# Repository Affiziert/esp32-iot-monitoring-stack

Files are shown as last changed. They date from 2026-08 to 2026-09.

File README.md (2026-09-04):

# ESP32 IoT Monitoring Stack

The project uses battery-powered ESP32-C3 boards as transmitters to measure temperature, relative humidity, and battery voltage. The sensor data is transmitted wirelessly via ESP-NOW to an ESP32-C3 receiver and forwarded via USB serial to a Raspberry Pi. A Python-based data bridge processes the received data and stores it in an InfluxDB database running in a Docker Compose environment.

This project can be used as a reference for integrating additional sensors and actuators.

---

## Overview

The goal of this project is to implement a lightweight and modular IoT monitoring stack using readily available hardware and open-source software.
The current implementation consists of the following components:

- ESP32-C3 transmitter node with a single Li-Ion cell (3.7 V), TP4056 charging module and voltage divider for battery voltage measurement
- SHT31 module for temperature and relative humidity measurement
- ESP32-C3 receiver node
- ESP-NOW wireless communication
- Raspberry Pi 4 as an edge gateway
- Python data bridge
- InfluxDB 2.x database

The modular architecture allows individual components to be modified or extended independently.

---

## Architecture

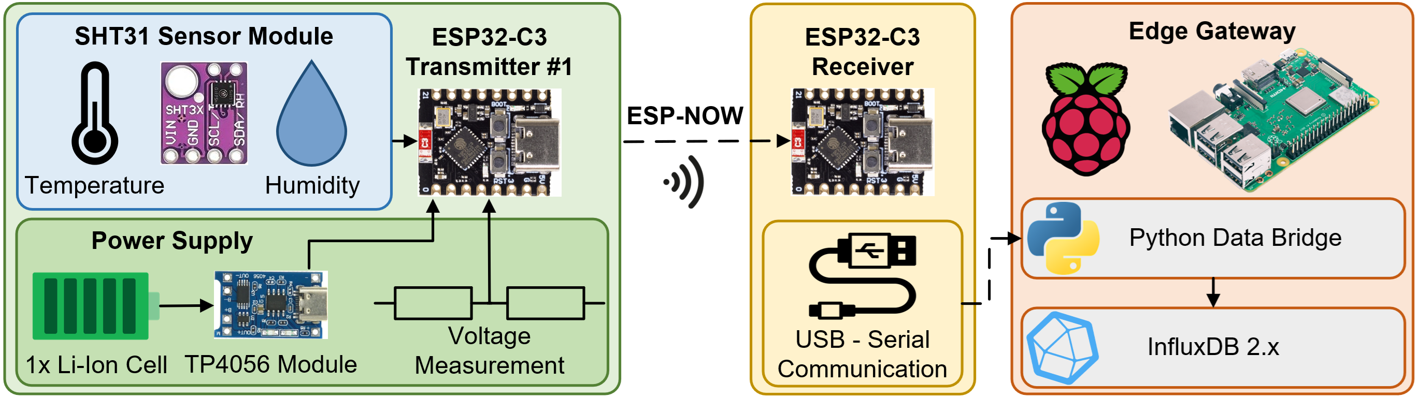
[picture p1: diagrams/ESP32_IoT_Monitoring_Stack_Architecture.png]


---

## Hardware Requirements

### Sensor Node

| Component | Quantity | Purpose |
|---|---|---|
| ESP32-C3 | 1 | Transmitter |
| SHT31 module | 1 | Temperature and relative humidity measurement |
| Li-Ion cell (3.7 V) | 1 | Power supply |
| 18650 battery holder  | 1 | Battery connection |
| TP4056 module | 1 | Li-Ion charging |
| Resistors | 2 | Voltage divider for battery voltage measurement (1 MΩ) |
| Capacitors | 1 | ADC input filtering (100 nF) |

### Receiver Node

| Component | Quantity | Purpose |
|---|---|---|
| ESP32-C3 | 1 | Receiver |
| USB cable | 1 | Serial connection to Raspberry Pi |

### Edge Gateway

| Component | Quantity | Purpose |
|---|---|---|
| Raspberry Pi 4 | 1 | Edge gateway |
| microSD card | 1 | Raspberry Pi OS and data |
| SSD (optional) | 1 | Additional storage / Docker data |
| USB cable (optional) | 1 | Connection to SSD |

---

## Software Requirements

### ESP32 Firmware

- Arduino IDE
- ESP32 Arduino Core 3.3.11
- Adafruit SHT31 library

### Raspberry Pi

- Raspberry Pi OS
- Python 3.x
- pyserial
- influxdb-client
- Docker Compose
  
### Database

- InfluxDB 2.x

---

## Setup

The setup consists of preparing and programming the ESP32-C3 nodes, assembling the sensor hardware, configuring the Raspberry Pi, and deploying the InfluxDB database and data bridge.

It is assumed that the following prerequisites are already fulfilled:

- Arduino IDE is installed and configured.
- The required ESP32 board support and libraries are installed.
- Raspberry Pi OS and Python 3, including the required libraries, are installed on the Raspberry Pi.
- Docker and Docker Compose are installed on the Raspberry Pi.

### ESP32 Receiver

The receiver must be configured and flashed before setting up the transmitter, as the transmitter requires the receiver's MAC address. If you do not know how to determine the MAC address, you can simply flash `ESP_MAC_Identifier.ino` to the receiver node. The MAC address will then be displayed via the serial monitor.

1. Download the `ESP-NOW_RX.ino` file and open it with the Arduino IDE.
2. Configure `wifi_channel` and `wifi_power`. Some boards may experience connection problems with transmission power above 15 dBm.
3. Flash the firmware to the ESP32-C3 receiver.

### ESP32 Transmitter

1. Download the `ESP-NOW_TX.ino` file and open it with the Arduino IDE.
2. Configure `wifi_channel` to match the receiver's channel and `wifi_power`.
3. Set `receiverMac[]` to match the MAC address of the receiver.
4. If you use more than one sensor node, assign a unique `sensor_ID` to each node.
5. Set the desired deep sleep interval (`sleep_time_sec`), number of transmissions per cycle (`trans_per_cycle`) and number of voltage measurements per cycle (`vol_meas_per_cycle`).
6. If you assemble the sensor node according to the example hardware setup, no further configuration is required. Otherwise, configure the I²C and ADC pins according to your hardware setup.
7. Flash the firmware to the ESP32-C3 transmitter.

### Hardware Setup

The sensor node can be assembled according to the following wiring diagram.

For the battery voltage measurement, the following components are used::
- Voltage divider: **2 × 1 MΩ** (680 kΩ resistors are also suitable)
- ADC filter capacitor: **1 × 100 nF**

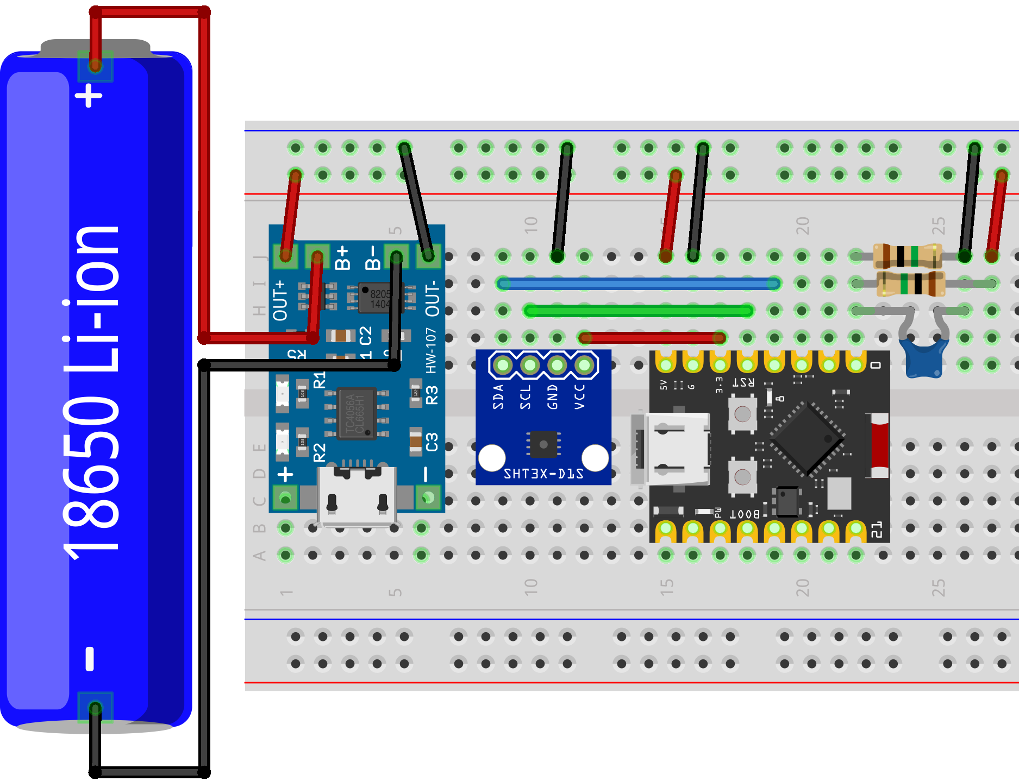
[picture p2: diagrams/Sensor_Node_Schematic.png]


### Raspberry Pi

1. Copy the `data_bridge.py` and `docker-compose.yml` to your Raspberry Pi.
2. Start the Docker Compose stack with:
   ```bash
   docker compose up -d
   ```
   The InfluxDB configuration and database data are stored in the `influxdb` directory next to the `docker-compose.yml` file. For long-term operation, it is recommended to store the InfluxDB data on an external SSD. Frequent database write operations wear out the SD card of the Raspberry Pi more quickly. The InfluxDB container is configured to restart automatically unless it is manually stopped.
3. Access the InfluxDB web interface on the Raspberry Pi (`http://localhost:8086`) or any device in your network (`http://<Raspberry_Pi_IP>:8086`) and configure InfluxDB for the first time. <br>
You will need the InfluxDB URL, organization, bucket, and API token to configure the `data_bridge.py`.
4. Now configure the `data_bridge.py` by adding the InfluxDB organization, bucket and API token created during the initial InfluxDB setup.
5. Set the baud rate to match the value used in the firmware and configure the serial port to which the ESP32-C3 receiver is connected. You can identify the available serial devices by running the following command and looking for the identifier of the receiver:
   ```bash
   ls -l /dev/serial/by-id/
   ```
6. Navigate to the directory containing `data_bridge.py` and start the program with:
   ```bash
   python3 data_bridge.py
   ```
7. Verify the received data by logging in to the InfluxDB web interface and checking the configured bucket in the Data Explorer for new data points.

### Automatic Startup (optional but recommended)
1. Copy the `data_bridge.service` file to the `/etc/systemd/system/` directory on the Raspberry Pi.
2. Open the service file and change the username and project directory according to your setup.
3. Enable and start the service with:
   ```bash
   sudo systemctl enable --now data_bridge.service
   ```
4. The Docker Compose stack is configured to restart automatically using the `restart: unless-stopped` option.
5. After rebooting the Raspberry Pi, the Docker Compose stack and the data bridge should start automatically. You can check the status of the data bridge with:
   ```bash
   sudo systemctl status data_bridge.service
   ```
   You are now ready to go!
   
---
   
## Components

### ESP32 Transmitter Node

The transmitter node collects environmental data and transmits a fixed-size payload of 8 bytes via ESP-NOW.
It periodically wakes from deep sleep, measures the connected sensors, transmits the data and returns to deep sleep.

### ESP32 Receiver Node

The receiver node continuously listens for ESP-NOW packets and converts the received data into a JSON object for transmission via USB serial.
The MAC address of the transmitter is obtained from the ESP-NOW reception information.

The JSON object contains:

- Sensor ID
- Transmitter MAC address
- Temperature
- Relative humidity
- Battery voltage

### Raspberry Pi Data Bridge

The Python data bridge runs on a Raspberry Pi and acts as the interface between the ESP32 receiver and InfluxDB.
Its main tasks are:

1. Read JSON data from the serial interface.
2. Parse and validate the received data.
3. Convert the data into an InfluxDB data point.
4. Write the data to the configured InfluxDB bucket.

### InfluxDB

InfluxDB is used as the time-series database for storing the sensor measurements.
The database is deployed using Docker Compose.

---

## Communication Protocol

The ESP-NOW communication uses a fixed-size binary payload of 8 bytes.

| Byte | Data Type | Description |
|---|---|---|
| 0 | `uint8_t` | Protocol Version |
| 1 | `uint8_t` | Sensor ID |
| 2–3 | `int16_t` | Temperature × 100 |
| 4–5 | `uint16_t` | Relative Humidity × 100 |
| 6–7 | `uint16_t` | Battery Voltage [mV] |

Temperature and relative humidity are transmitted as scaled integer values to reduce the payload size and avoid transmitting floating-point values.
The payload structure is explicitly packed and its size is checked at compile time.

---

## Debugging

Both ESP32 nodes provide optional serial debug output.

The debug output can be used to identify issues such as:

- ESP-NOW initialization failures
- Invalid payload size
- Protocol version mismatches
- Invalid sensor IDs
- ESP-NOW transmission failures
- Sensor initialization failures
- Firmware and protocol version information
  
Debug output can be enabled using:

```cpp
#define DEBUG_SERIAL 1
```

Normal operation:

```cpp
#define DEBUG_SERIAL 0
```

The serial interface currently operates at:

```text
115200 baud
```

### Versioning

#### Firmware Version

The firmware version identifies the software version installed on an ESP32.
It is independent of the communication protocol version and can be used to identify the exact firmware running on a device during debugging.

#### Protocol Version

The protocol version identifies the format of the data transmitted between ESP32 transmitter and receiver.
The receiver validates the protocol version before processing a packet.

A protocol version change is required if the structure or interpretation of the transmitted payload changes in a way that is incompatible with the existing receiver implementation.

---

### Planned

- [ ] Sensor Node ID verification
- [ ] Receiver logic for multiple transmissions per cycle
- [ ] Grafana Dashboard
- [ ] Protocol Version 2 for generic sensor integration
- [ ] MQTT implementation between Receiver and Raspberry Pi

---

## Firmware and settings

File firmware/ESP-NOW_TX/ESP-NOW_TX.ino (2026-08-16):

/*
 * ESP-NOW TX Node
 *
 * ArduinoIDE configuration:
 * - ESP32 Arduino Core: 3.3.11
 * - Board: ESP32C3 Dev Module
 * - CPU Frequency: 160 MHz
 * - USB CDC On Boot: Enabled
 * - Serial Baud Rate: 115200
 */

#include <Arduino.h>
#include <WiFi.h>
#include <esp_now.h>
#include <esp_wifi_types.h>
#include "esp_sleep.h"

#include <Wire.h>
#include <Adafruit_SHT31.h>

// =================== Device Config ===================
// Firmware version
static constexpr char firmware_version[] = "1.0.0";

// Sensor ID and protocol version
static constexpr uint8_t  sensor_ID          = 1;   // Make unique for each ESP device (0–255)
static constexpr uint8_t  protocol_version   = 1;   // Must match the receiver version

// Receiver MAC address 
uint8_t receiverMac[] = { 0x00, 0x00, 0x00, 0x00, 0x00, 0x00 };

// Wi-Fi settings
static const uint8_t wifi_channel = 6; // Wi-Fi channel
static constexpr wifi_power_t wifi_power = WIFI_POWER_15dBm; // Transmission power. Some ESP32-C3 boards show an unstable connection above transmission power WIFI_POWER_15dBm.

// Number of transmissions per transmission cycle
static const uint8_t trans_per_cycle = 1;

// I2C pin configuration for SHT31 sensor
static const int I2C_SDA = 3;
static const int I2C_SCL = 4;

// SHT31 I2C address (usually 0x44, alternatively 0x45)
static const uint8_t SHT31_addr = 0x44;

// ADC pin configuration for battery voltage measurement
static const int bat_vol_pin = 0;

// Number of voltage measurements per transmission cycle (to calculate the average)
static const uint8_t vol_meas_per_cycle = 16;

// Deep Sleep time in seconds
static constexpr uint32_t sleep_time_sec = 600;   // 10 minutes 

// Enable serial debug output
// 0 = normal operation
// 1 = debug mode
#define DEBUG_SERIAL 0 

// =================== Payload Definition ===================
// Data structure transmitted via ESP-NOW
// Packed to ensure a fixed payload size of 8 bytes
struct __attribute__((packed)) Payload {
  uint8_t  version;
  uint8_t  sensorId;
  int16_t  temp;
  uint16_t humidity;
  uint16_t battery;
};

static_assert(sizeof(Payload) == 8,"Payload size must be 8 bytes");

// =================== Runtime Variables ===================
// Sensor and battery measurements
int16_t  t_x100;
uint16_t rh_x100;
uint16_t bat_voltage;

// =================== Sensors ===================
// Create a sensor instance
Adafruit_SHT31 sht31 = Adafruit_SHT31();

// =================== Function Implementations ===================
// Initialize Deep Sleep Function
static void DeepSleep(){
  esp_now_deinit();   // Deinitialization for Deep Sleep
  WiFi.mode(WIFI_OFF);
  esp_sleep_enable_timer_wakeup((uint64_t)sleep_time_sec * 1000000ULL); // Converting seconds to microseconds
  esp_deep_sleep_start();
}

// Initialize ESP-NOW Function
static void initEspNow() {
  WiFi.mode(WIFI_STA); // Set Wi-Fi settings
  WiFi.setChannel(wifi_channel);
  WiFi.setTxPower(wifi_power);

  if (esp_now_init() != ESP_OK) { // Initialize ESP-NOW
    if (DEBUG_SERIAL == 1){
      delay (100);
      Serial.println("ESP-NOW: Initialising failed");
    }
    while (true) {
      delay(1000);
    }
  }

  esp_now_peer_info_t peer = {}; // Configure the ESP-NOW peer for unicast communication
  memcpy(peer.peer_addr, receiverMac, 6); // Set receiver MAC address
  peer.channel = wifi_channel; // Set Wi-Fi channel
  peer.encrypt = false; // Set encryption
  
  // Add receiver as an ESP-NOW peer
  if (esp_now_add_peer(&peer) != ESP_OK) {
    if (DEBUG_SERIAL == 1){
      delay (100);
      Serial.println("ESP-NOW: Add peer failed");
    }
    while (true) {
      delay(1000);
    };
  }
}

// Initialize Sensor Function
static void initSht31() {
  Wire.begin(I2C_SDA, I2C_SCL); // I2C connection to the sensor
  Wire.setTimeOut(100); // Timeout after 100 ms

  if (!sht31.begin(SHT31_addr)) { // Initialize sensor
    if (DEBUG_SERIAL == 1){
      delay (100);
      Serial.println("SHT31: Not found");
    }
    while (true) {
      delay(1000);
    };
  }
}

// Sensor Measurement Function
static void readSht31Scaled(int16_t &t_x100, uint16_t &rh_x100) {
  float temp = sht31.readTemperature(); // Read temperature
  float humidity = sht31.readHumidity(); // Read humidity

  if (isnan(temp) || isnan(humidity)) { // Check if temp or humidity is NaN
    t_x100  = INT16_MIN; // Flag value
    rh_x100 = 0xFFFF; // Flag value
    return;
  }

  // Convert floating-point values to scaled integers to reduce payload size
  // Temperature and humidity are stored with a resolution of 0.01 °C / %
  long temp_scaled = lroundf(temp * 100.0f);
  long humidity_scaled = lroundf(humidity * 100.0f);
  
  // Limit values to the range of the target data types
  if (temp_scaled >  32767) temp_scaled =  32767;
  if (temp_scaled < -32768) temp_scaled = -32768;
  if (humidity_scaled < 0) humidity_scaled = 0;
  if (humidity_scaled > 65535) humidity_scaled = 65535;

  t_x100  = (int16_t)temp_scaled;
  rh_x100 = (uint16_t)humidity_scaled;
}

// Battery Voltage Measurement Function
static void readBattery(uint16_t &bat_voltage){
  uint32_t sum = 0;

  for (int i = 0; i < vol_meas_per_cycle; i++) { 
    sum += analogReadMilliVolts(bat_vol_pin);
    delay(2);
  }
  uint32_t adcVoltage_mV = sum / vol_meas_per_cycle; // Calculate average

  // Reconstruct battery voltage from the 1:1 voltage divider
  // Divider: 1 MΩ : 1 MΩ, with 100 nF filtering capacitor
  bat_voltage = adcVoltage_mV * 2;

  if (DEBUG_SERIAL == 1){
  Serial.print("Battery: ");
  Serial.print(bat_voltage);
  Serial.println(" mV");
  }
}

// Send Payload Function
static void send_payload(){
  Payload p; // Build payload with device information and sensor data
  p.version   = protocol_version;
  p.sensorId  = sensor_ID;

  readSht31Scaled(t_x100, rh_x100); // Get sensor data
  p.temp      = t_x100;
  p.humidity  = rh_x100;

  readBattery(bat_voltage); // Get battery voltage in mV
  p.battery   = bat_voltage;

  // Repeat transmission to increase the probability of successful reception
  // The receiver currently does not filter duplicate packets
  for (int i = 0; i < trans_per_cycle; i++) {
    esp_now_send(receiverMac, (uint8_t*)&p, sizeof(p));
    delay(50);
  }
}

// ESP-NOW callback handler
void onSent(const wifi_tx_info_t* info, esp_now_send_status_t status) {
  if (DEBUG_SERIAL == 1) {
    Serial.println(status == ESP_NOW_SEND_SUCCESS ? "TX: OK" : "TX: FAIL - Is the receiver ok?");
  }
}

void setup() {
  if (DEBUG_SERIAL == 1){   // Initialize serial interface for debug mode
    Serial.begin(115200);
    delay (1000);
  }

  initEspNow();  // Initialize ESP-NOW
  initSht31(); // Initialize SHT31 sensor

  if (DEBUG_SERIAL == 1){   // Register ESP-NOW transmission callback
    esp_now_register_send_cb(onSent);
    delay (100);
  }

  send_payload();   // Read sensor data and transmit payload

  // Initialization completed successfully
  if (DEBUG_SERIAL == 1){
    Serial.println("ESP-NOW TX Node initialized successfully.");
    Serial.print("Firmware version: ");
    Serial.println(firmware_version);

    Serial.print("Protocol version: ");
    Serial.println(protocol_version);

    Serial.print("Sensor ID: ");
    Serial.println(sensor_ID);

    delay (100);
  }

  DeepSleep();   // Enter deep sleep until next measurement cycle

}

void loop() {}

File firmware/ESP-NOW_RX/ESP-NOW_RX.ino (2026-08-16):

/*
 * ESP-NOW RX Node
 *
 * ArduinoIDE configuration:
 * - ESP32 Arduino Core: 3.3.11
 * - Board: ESP32C3 Dev Module
 * - CPU Frequency: 80 MHz
 * - USB CDC On Boot: Enabled
 * - Serial Baud Rate: 115200
 */

#include <Arduino.h>
#include <WiFi.h>
#include <esp_now.h>

// =================== Device Config ===================
// Firmware version
static constexpr char firmware_version[] = "1.0.0";

// Protocol version
static constexpr uint8_t  protocol_version   = 1;   // Must match the transmitter version

// Wi-Fi settings
static const uint8_t wifi_channel = 6; // Wi-Fi channel
static constexpr wifi_power_t wifi_power = WIFI_POWER_15dBm; // Transmission power. Some ESP32-C3 boards show an unstable connection above transmission power WIFI_POWER_15dBm.

// Maximum sensor ID value (because uint8_t range: 0-255)
static constexpr uint8_t max_sensor_ID = 255; // Reserved for future sensor ID validation

// Enable serial debug output
// 0 = normal operation
// 1 = debug mode
#define DEBUG_SERIAL 0 

// =================== Payload Definition ===================
// Data structure transmitted via ESP-NOW
// Packed to ensure a fixed payload size of 8 bytes
struct __attribute__((packed)) Payload {
  uint8_t  version;
  uint8_t  sensorId;
  int16_t  temp;
  uint16_t humidity;
  uint16_t battery;
};

static_assert(sizeof(Payload) == 8,"Payload size must be 8 bytes");

// =================== Function Implementations ===================
// Initialize ESP-NOW Function
static void initEspNow() {
  WiFi.mode(WIFI_STA); // Set Wi-Fi settings
  WiFi.setChannel(wifi_channel);
  WiFi.setTxPower(wifi_power);

  if (esp_now_init() != ESP_OK) { // Initialize ESP-NOW
    if (DEBUG_SERIAL == 1){
      delay (100);
      Serial.println("ESP-NOW: Initialising failed");
    }
    while (true) {
      delay(1000);
    }
  }
}

// ESP-NOW callback handler
void onRecv(const esp_now_recv_info_t* info, const uint8_t* data, int len) {
  if (len != (int)sizeof(Payload)) {  // Ignore packets with unexpected payload size
    if (DEBUG_SERIAL == 1){
     Serial.println("Callback ERROR: Invalid payload size");
    } 
    return;
  }

  Payload p;
  memcpy(&p, data, sizeof(p)); // Copy received bytes into payload structure

  if (p.version != protocol_version) {  // Ignore packets with unsupported protocol version
    if (DEBUG_SERIAL == 1) {
     Serial.println("Callback ERROR: Protocol version mismatch");
    }
    return;
  }

  if (p.sensorId == 0) {  // Ignore packets with invalid sensor ID
   if (DEBUG_SERIAL == 1) {
      Serial.println("Callback ERROR: Invalid sensor ID");
    }
    return;
  }

  const uint8_t* mac = info->src_addr; // Get transmitter MAC address

  Serial.printf( // Output received data as JSON for serial processing
  "{\"id\":%u,"
  "\"mac\":\"%02X:%02X:%02X:%02X:%02X:%02X\","
  "\"temp\":%.2f,\"rh\":%.2f,\"batt\":%u}\n",
  p.sensorId,
  mac[0], mac[1], mac[2], mac[3], mac[4], mac[5],
  p.temp / 100.0f,
  p.humidity / 100.0f,
  p.battery
  );
}

void setup() {
  Serial.begin(115200); // Initialize serial interface
  while (!Serial) {}

  initEspNow();  // Initialize ESP-NOW
  esp_now_register_recv_cb(onRecv); // Register ESP-NOW transmission callback
  delay (100);
  
  // Initialization completed successfully
  if (DEBUG_SERIAL == 1){
    Serial.println("ESP-NOW RX Node initialized successfully.");
    Serial.print("Firmware version: ");
    Serial.println(firmware_version);

    Serial.print("Protocol version: ");
    Serial.println(protocol_version);

    delay (100);
  }
}

void loop() {}

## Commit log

2026-08-16 Rename project title to 'ESP-NOW-sensor-monitoring'
2026-08-16 Complete rework for GitHub
    [ESP-NOW_RX.ino]
2026-09-04 Added architecture and schematic pictures
    [Sensor_Node_Schematic.fzz]
